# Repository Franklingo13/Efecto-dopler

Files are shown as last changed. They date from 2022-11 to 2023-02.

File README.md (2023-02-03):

# Radar de Velocidad Basado en el Efecto Doppler

Para este proyecto se emplea el efecto Doppler para calcular la velocidad de un objeto en base a la diferencia de frecuencias entre la enviada y la recibida.
El dispositivo empleado como transmisor y receptor es el sensor de movimiento CDM324, el cual funciona a una frecuecia de 24GHz. Este sensor también incorpora un mezclador de altas frecuencias y su salida es de unos pocos milivoltios, razón por la cual debe ser amplificada.

Se basó en el siguiente trabajo: https://github.com/limpkin/cdm324_backpack.

## _Primera Versión_
- Usa arduino Mega.
- Calcula la frecuencia recibida mediante usando la función _pulsein_.
- Presenta la velocidad en una pequeña pantalla OLED

### Amplificador 

Para el amplificador se usó el operacional LM358 alimentado a 5V y consta de dos etapas, la primera pre-amplifica la señal y en la segunda se obtiene una señal cuadrada. 
La simulación en Proteus de este circuito se encuentra en _Sim_Proteus/Circuito_amplificador.pdsprj_

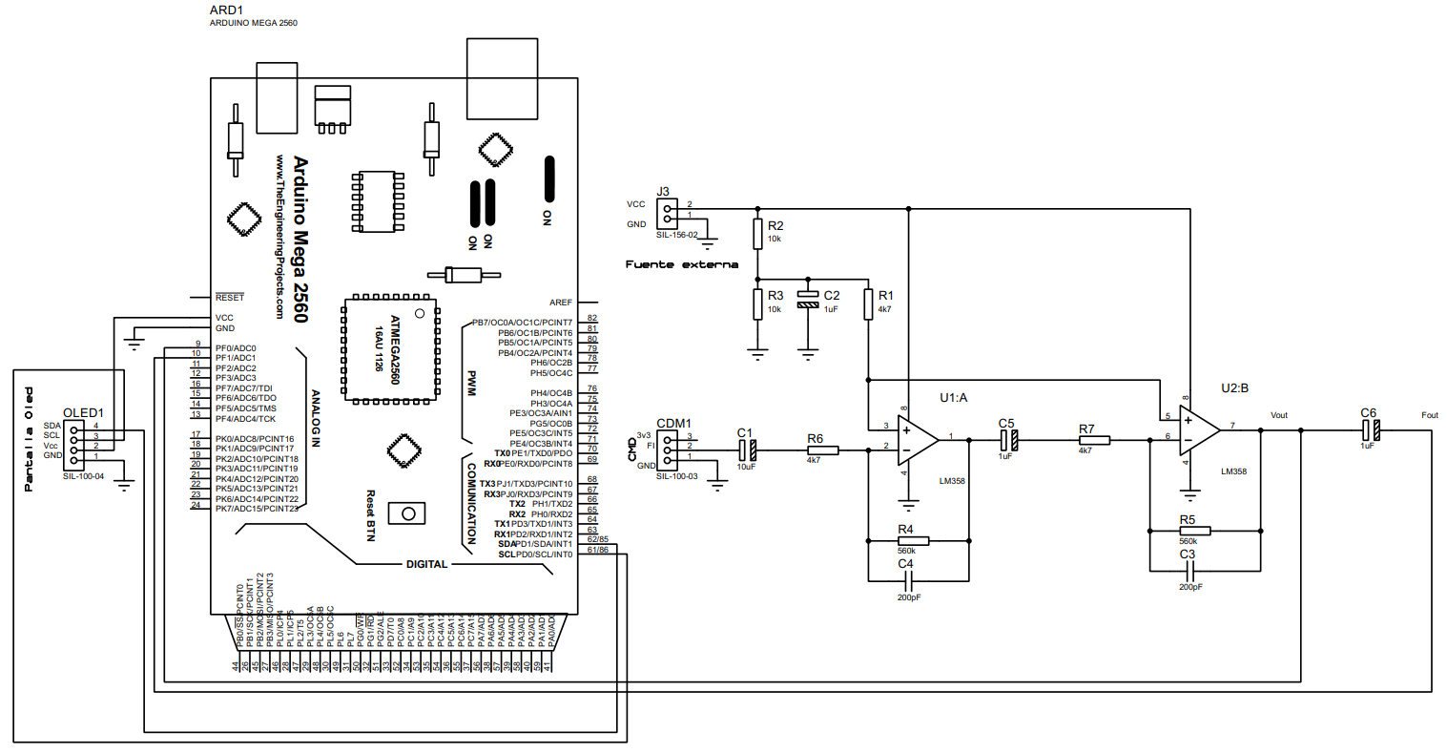
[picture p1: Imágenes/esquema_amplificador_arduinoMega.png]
Esquema de la primera versión del amplificador


### Código arduino

Para calcular la frecuencia de un objeto se mide el ancho de cada pulso de la señal recibida en el Arduino para calcular el periodo de la señal y así tener su frecuencia Doppler, con la que ya se puede calcular la velocidad. El código para implementar este método está en _Codigo arduino/contador_frecuencia_ .

### Placa PCB
En la carpeta de _Esquemáticos_ se puede encontrar el gerber de la siguiente placa PCB.

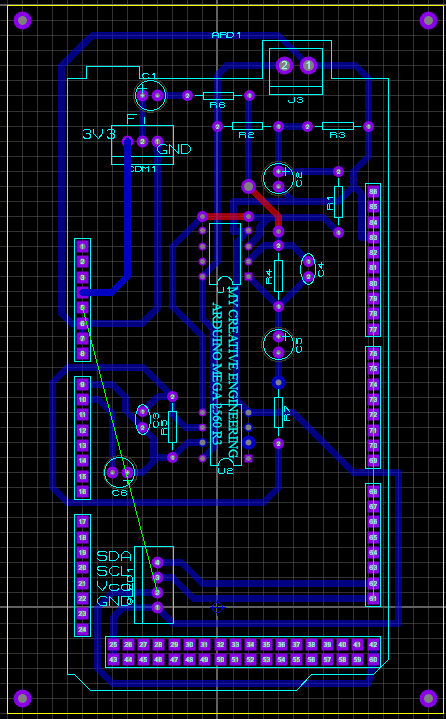
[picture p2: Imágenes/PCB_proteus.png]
Priemra versión de placa PCB


### Soporte 3D

Las piezas para el soporte impreso en 3D mostrado a continuación se encuentran en la carpeta _Piezas_.
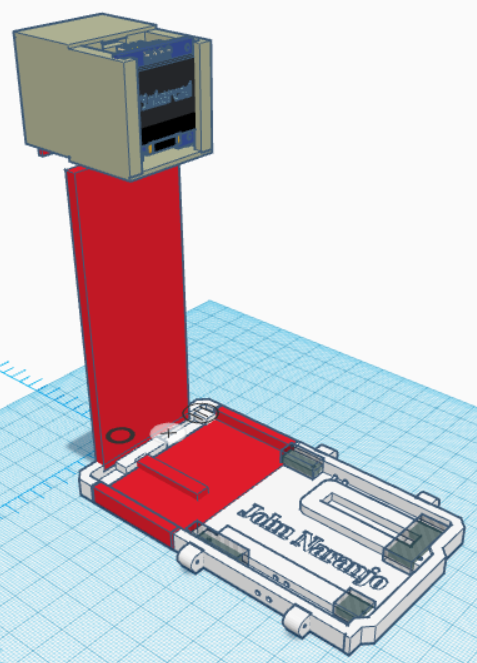
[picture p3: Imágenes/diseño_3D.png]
Primera versión del soporte


## _Segunda versión_
- Usa un ESP32.
- Calcula la frecuencia recibida mediante FFT.
- Presenta la velocidad en una pequeña pantalla OLED
- Envia los datos a un servicio en la nube para poder revisar la velocidad desde cualquier dispositivo con acceso a internet.

### Amplificador 

El esquema del amplificador y sus conexiones con el ESP32 se muestran a continuación.

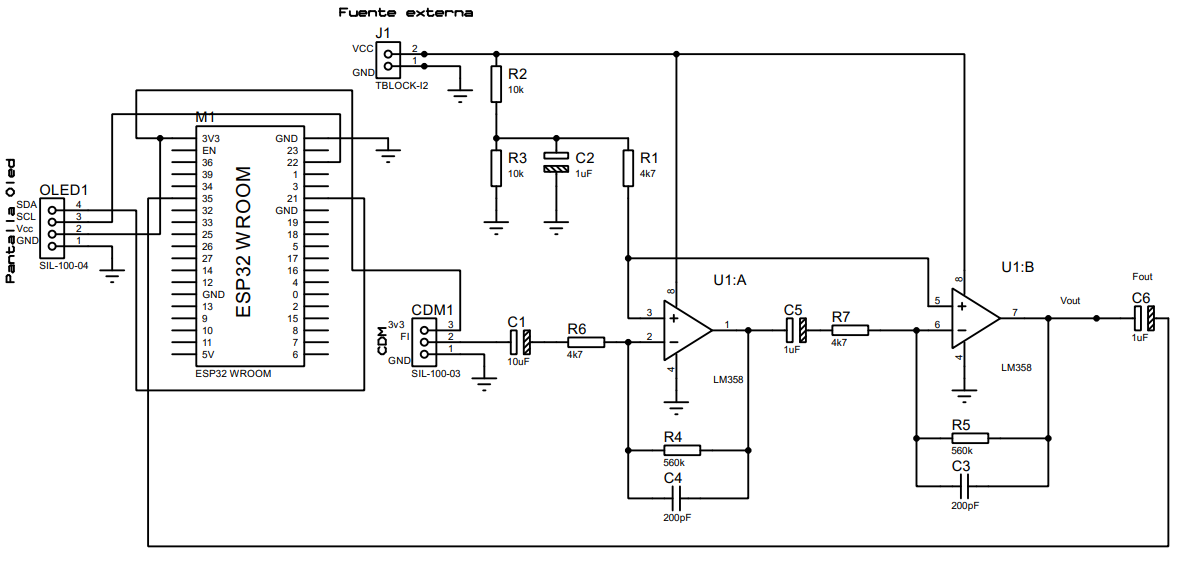
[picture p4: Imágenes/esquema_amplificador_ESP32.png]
Esquema de la segunda versión del amplificador


### Código arduino

Para encontrar la velocidad se calcula la FFT de la señal recibida empleando la librería arduinoFFT.h, además de presentar los datos en una pantalla OLED, también los envía al servicio en la nube de Thinger.io.  El código para implementar este método está en _Codigo arduino/final_esp32_FFT_ .

### Placa PCB
La versión final de la placa PCB se muestra a continuación y sus archivos Gerber están en la carpeta de _Esquemáticos_
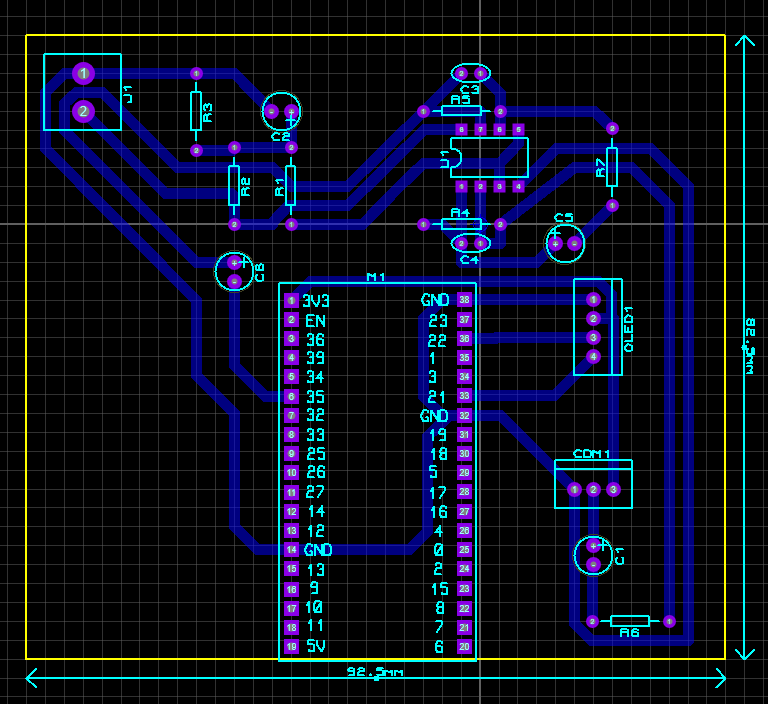
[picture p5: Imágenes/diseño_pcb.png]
segunda versión de placa PCB


### Soporte 3D

Las piezas de la segunda versión del soporte se encuentran en la carpeta _Piezas radar final_ESP32_.

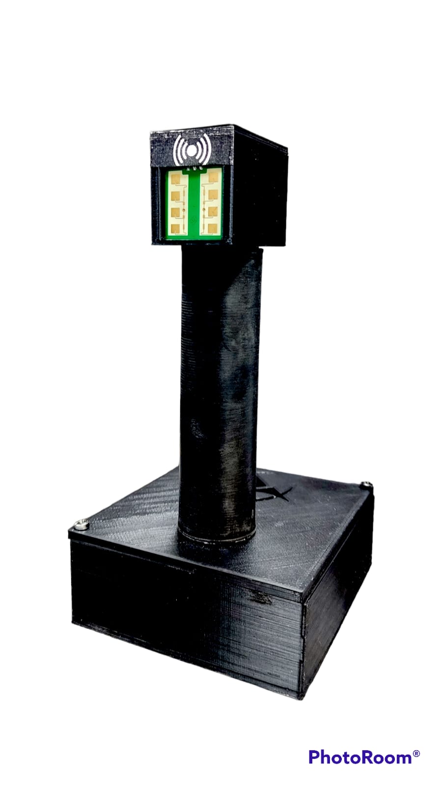
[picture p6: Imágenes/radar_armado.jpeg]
Segunda versión del soporte


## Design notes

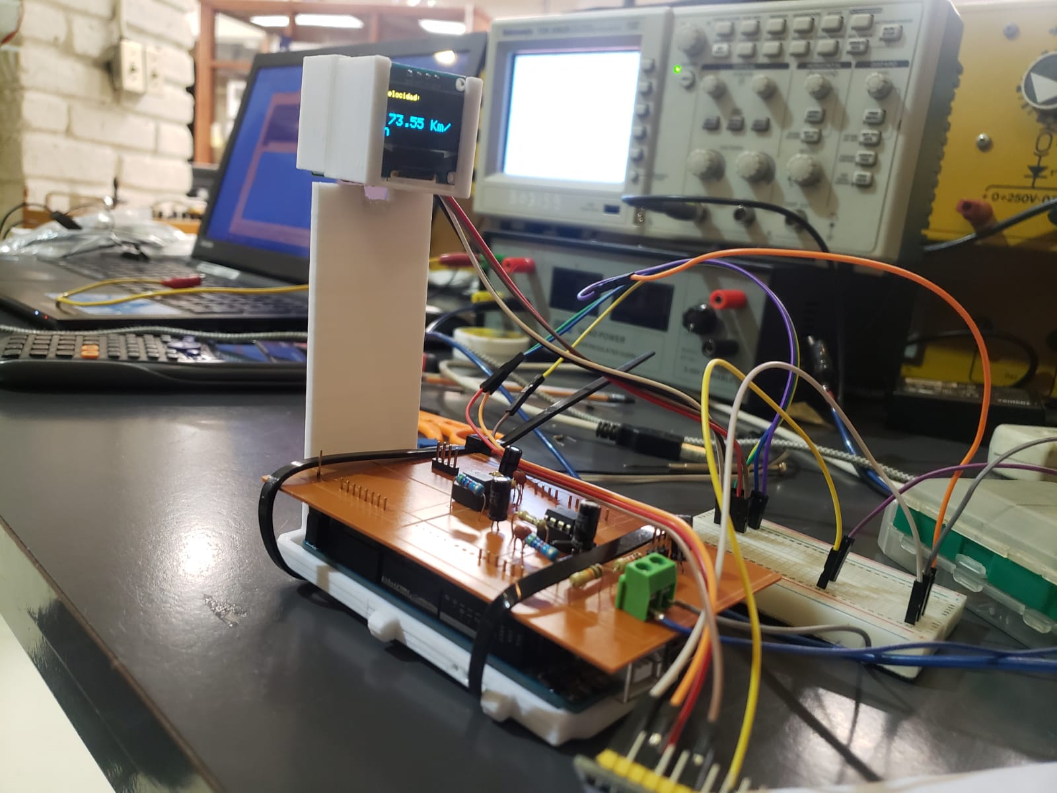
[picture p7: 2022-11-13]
Imágenes/diseño_implementado.jpeg

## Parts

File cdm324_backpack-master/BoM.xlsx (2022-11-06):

 | Prototype Quantity | 10
Item | References | Qty | Manufacturer P/N | Manufacturer | Description | Package | Internet Link | Home ID | Part Status
1 | U1 | 1 | OPA2365AIDR | Texas Instruments | IC OPAMP GP 50MHZ RRO 8SOIC | 8-SOIC | http://www.digikey.com/product-detail/en/OPA2365AIDR/296-31704-1-ND/3505181 | ---- | Active
2 | R2 R3 R10 R11 R1 | 5 | RC0805FR-0710KL | Yageo | RES SMD 10K OHM 1% 1/8W 0805 | 0805 | http://www.digikey.com/product-detail/en/yageo/RC0805FR-0710KL/311-10.0KCRCT-ND/730482 | ---- | Active
3 | FB1 | 1 | HZ0805D102R-10 | Laird-Signal Integrity Products | FERRITE BEAD 1 KOHM 0805 1LN | 0805 (2012 Metric) | http://www.digikey.com/product-detail/en/HZ0805D102R-10/240-2397-1-ND/806757 | ---- | Active
4 | P2 | 1 | PPPC031LFBN-RC | Sullins Connector Solutions | CONN HEADER FEMALE 3POS .1" GOLD |  | http://www.digikey.com/product-detail/en/sullins-connector-solutions/PPPC031LFBN-RC/S7036-ND/810175 | ---- | Active
5 | C3 C4 C1 C2 C8 C5 C9 C11 C10 | 9 | CL21B106KOQNNNE | Samsung Electro-Mechanics America, Inc. | CAP CER 10UF 16V X7R 0805 | 0805 (2012 Metric) | http://www.digikey.com/product-detail/en/samsung-electro-mechanics-america-inc/CL21B106KOQNNNE/1276-2872-1-ND/3890958 | ---- | Active
6 | R4 R5 R6 | 3 | RC0805FR-074K7L | Yageo | RES SMD 4.7K OHM 1% 1/8W 0805 | 0805 | http://www.digikey.com/product-detail/en/yageo/RC0805FR-074K7L/311-4.70KCRCT-ND/730876 | ---- | Active
7 | R7 R8 | 2 | ERJ-6ENF5903V | Panasonic Electronic Components | RES SMD 590K OHM 1% 1/8W 0805 | 0805 | http://www.digikey.com/product-detail/en/panasonic-electronic-components/ERJ-6ENF5903V/P590KCCT-ND/119773 | ---- | Active
8 | C6 C7 | 2 | CC0805JRNPO9BN271 | Yageo | CAP CER 270PF 50V NPO 0805 | 0805 (2012 Metric) | http://www.digikey.com/product-detail/en/yageo/CC0805JRNPO9BN271/311-1116-1-ND/303026 | ---- | Active
9 | U2 | 1 | MAX9031AUK+T | Maxim Integrated | IC COMPARATOR VOLT SGL SOT23-5 | SOT-23-5 | http://www.digikey.com/product-detail/en/MAX9031AUK%2BT/MAX9031AUK%2BTCT-ND/774161 | ---- | Active
10 | R9 | 1 | RC0805FR-078K2L | Yageo | RES SMD 8.2K OHM 1% 1/8W 0805 | 0805 | http://www.digikey.com/product-detail/en/yageo/RC0805FR-078K2L/311-8.20KCRCT-ND/731094 | ---- | Active
11 | D1 | 1 | S1B-13-F | Diodes Incorporated | DIODE GEN PURP 100V 1A SMA | SMA | http://www.digikey.com/product-detail/en/diodes-incorporated/S1B-13-F/S1B-FDICT-ND/725064 | ---- | Active
12 | Q1 | 1 | DMP3098L-7 | Diodes Incorporated | MOSFET P-CH 30V 3.8A SOT23-3 | SOT-23-3 | http://www.digikey.com/product-detail/en/diodes-incorporated/DMP3098L-7/DMP3098LDICT-ND/1964773 | ---- | Active
13 | P1 | 1 |  |  | Standard 5x1 0.1" straight male header
 | Total: | 28

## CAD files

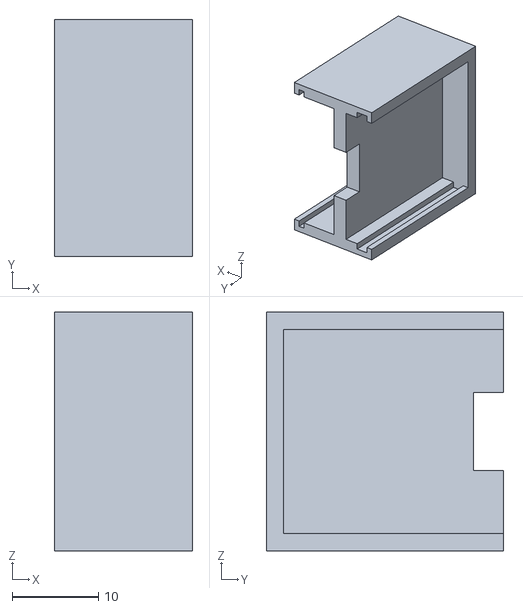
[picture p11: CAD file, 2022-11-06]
cdm324_backpack-master/mechanics/assembly.STL
16.0 x 27.5 x 27.7

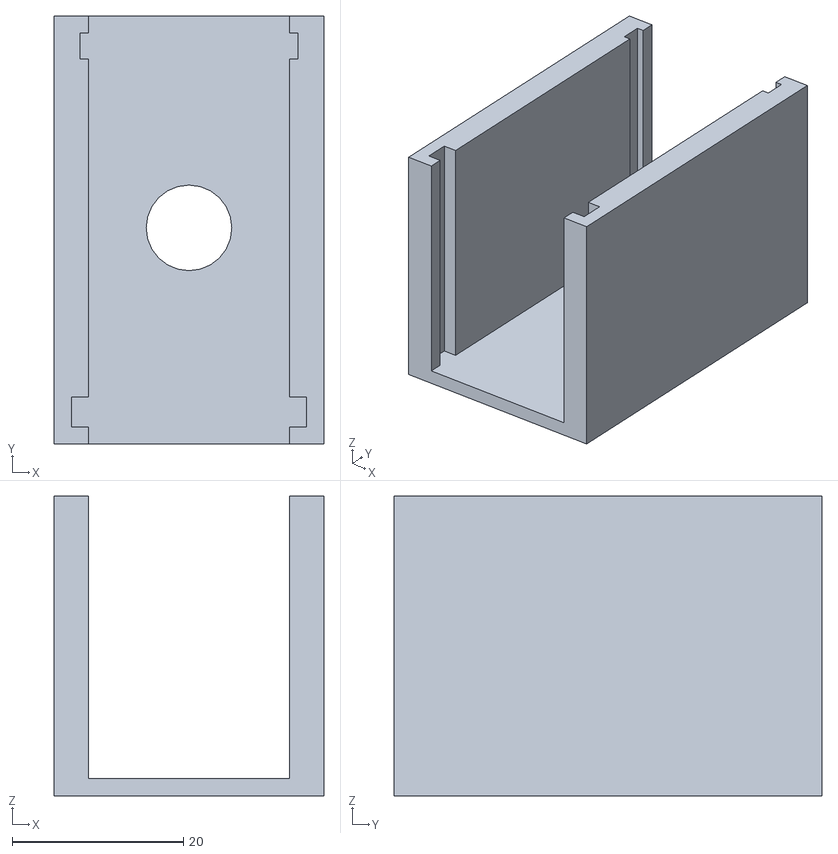
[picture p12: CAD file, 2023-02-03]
Piezas radar final_ESP32/Cabezal.stl
31.5 x 50.0 x 35.0

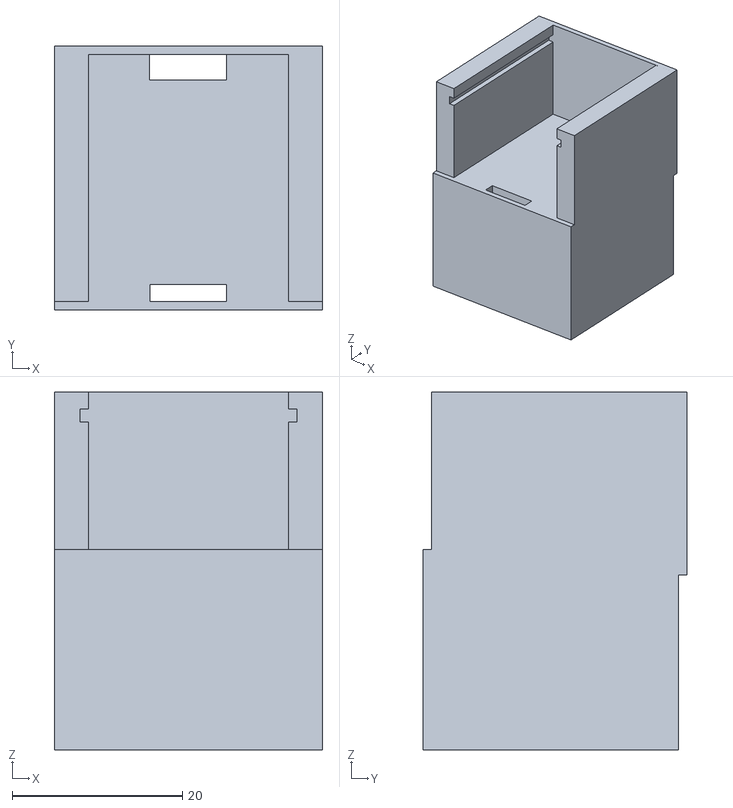
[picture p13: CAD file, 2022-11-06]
Piezas/piezas_final-BodyPad002.stl
31.5 x 31.0 x 42.0

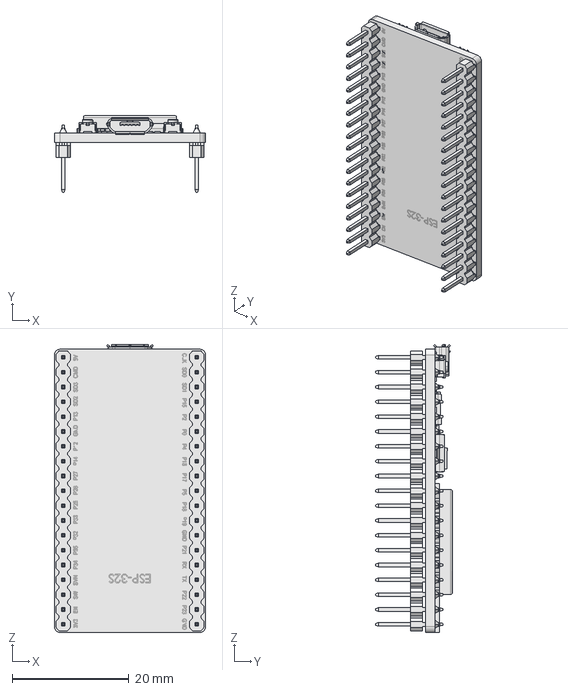
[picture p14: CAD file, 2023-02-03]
Piezas radar final_ESP32/esp32_3d.FCStd
25.9 x 13.1 x 49.3 mm

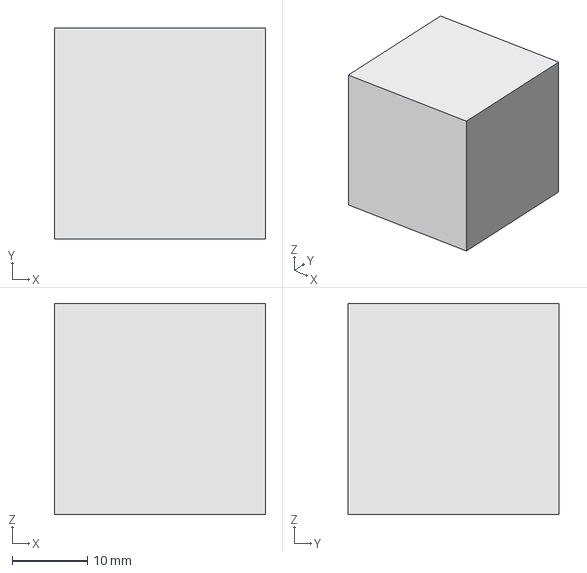
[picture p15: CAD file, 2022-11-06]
Piezas/pieza1.FCStd
28.0 x 28.0 x 28.0 mm

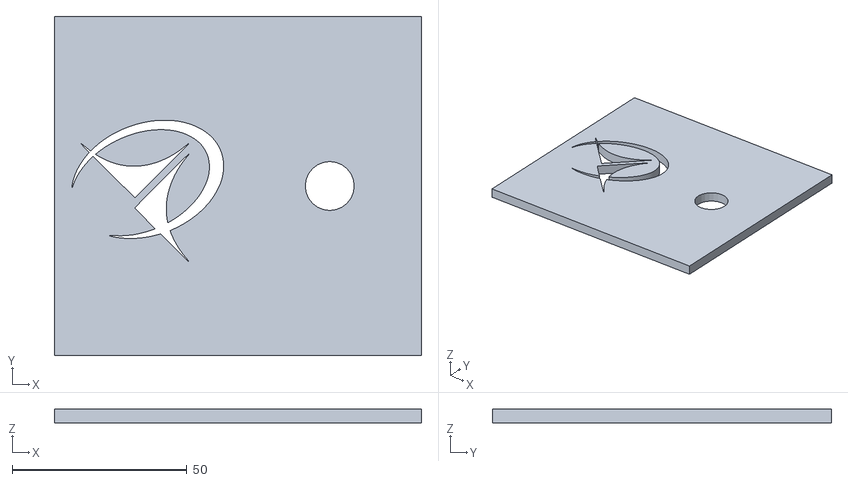
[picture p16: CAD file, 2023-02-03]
Piezas radar final_ESP32/Tapa.stl
105.0 x 97.0 x 4.00

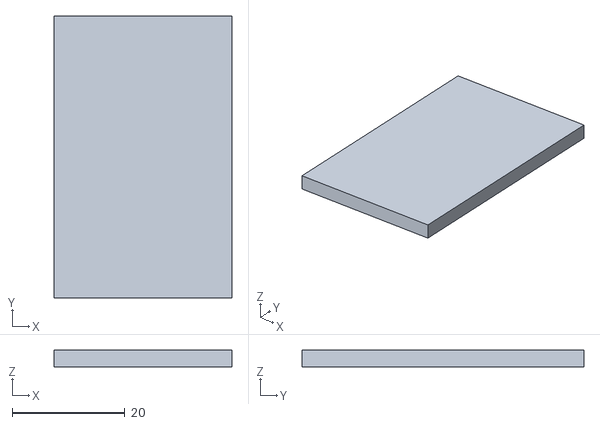
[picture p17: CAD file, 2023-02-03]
Piezas radar final_ESP32/TapaCabezal.stl
31.5 x 50.0 x 3.00

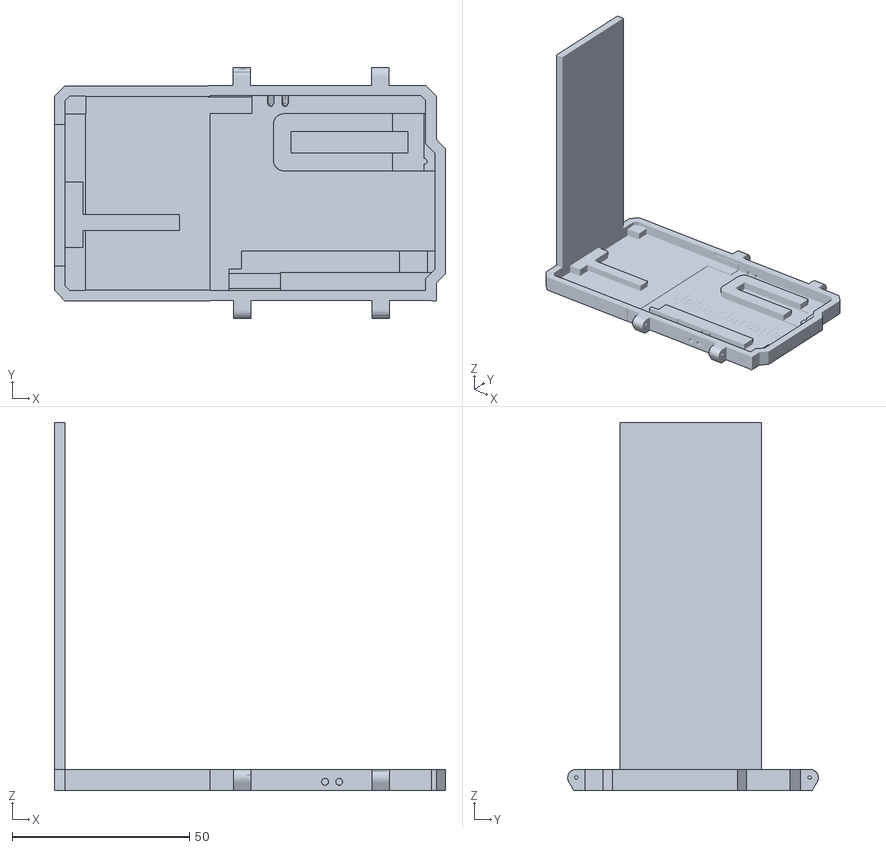
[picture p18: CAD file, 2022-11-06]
Piezas/base_arduino.stl
110.4 x 70.8 x 104.0

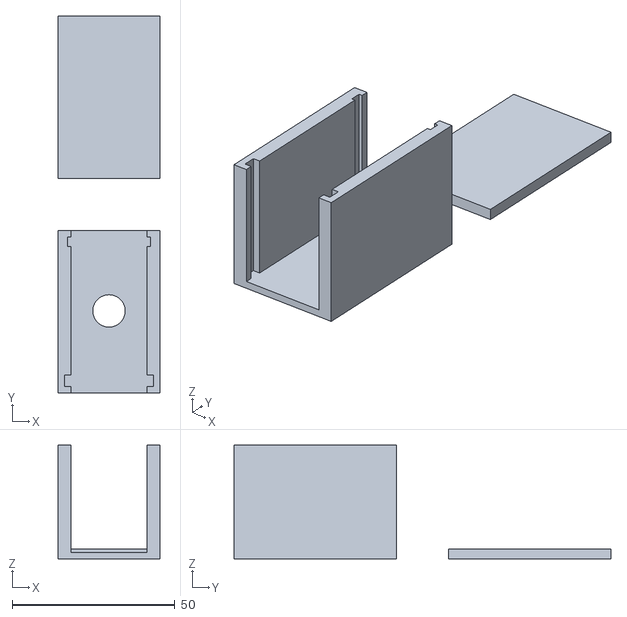
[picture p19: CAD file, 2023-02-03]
Piezas radar final_ESP32/cabezal_tapa.stl
31.5 x 116.0 x 35.0

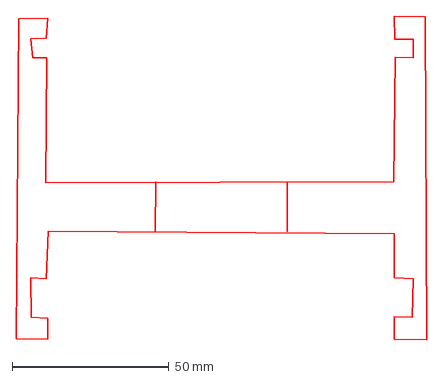
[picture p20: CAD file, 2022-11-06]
Piezas/medidas.dxf
130.8 x 103.3 mm

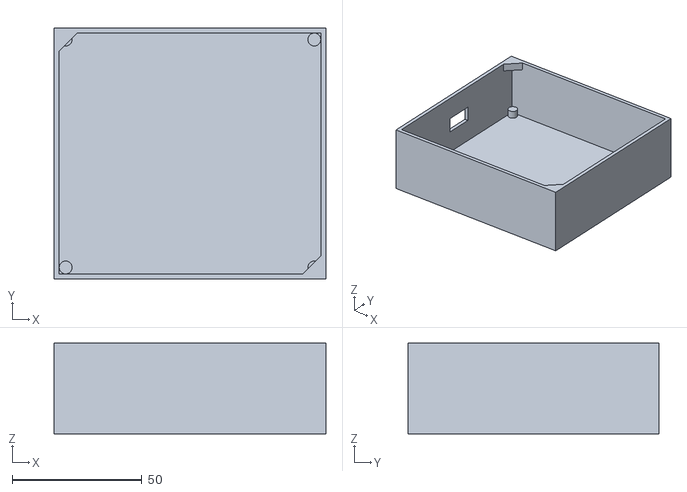
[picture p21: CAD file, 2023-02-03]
Piezas radar final_ESP32/Base.stl
105.0 x 97.0 x 35.0

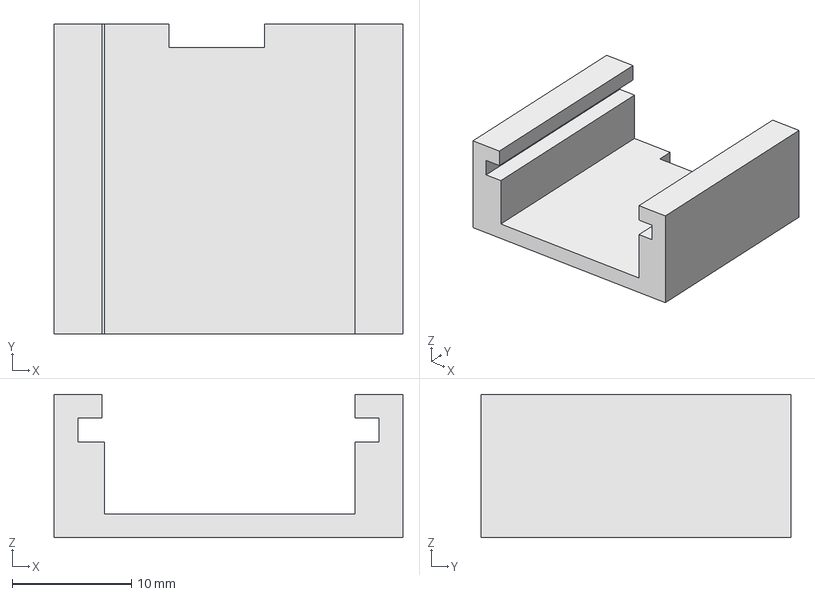
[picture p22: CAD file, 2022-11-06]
Piezas/extrusión.FCStd
29.2 x 26.0 x 12.0 mm

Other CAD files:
Piezas/pieza_sensor_oles.stl
Piezas/piezas_final.FCStd

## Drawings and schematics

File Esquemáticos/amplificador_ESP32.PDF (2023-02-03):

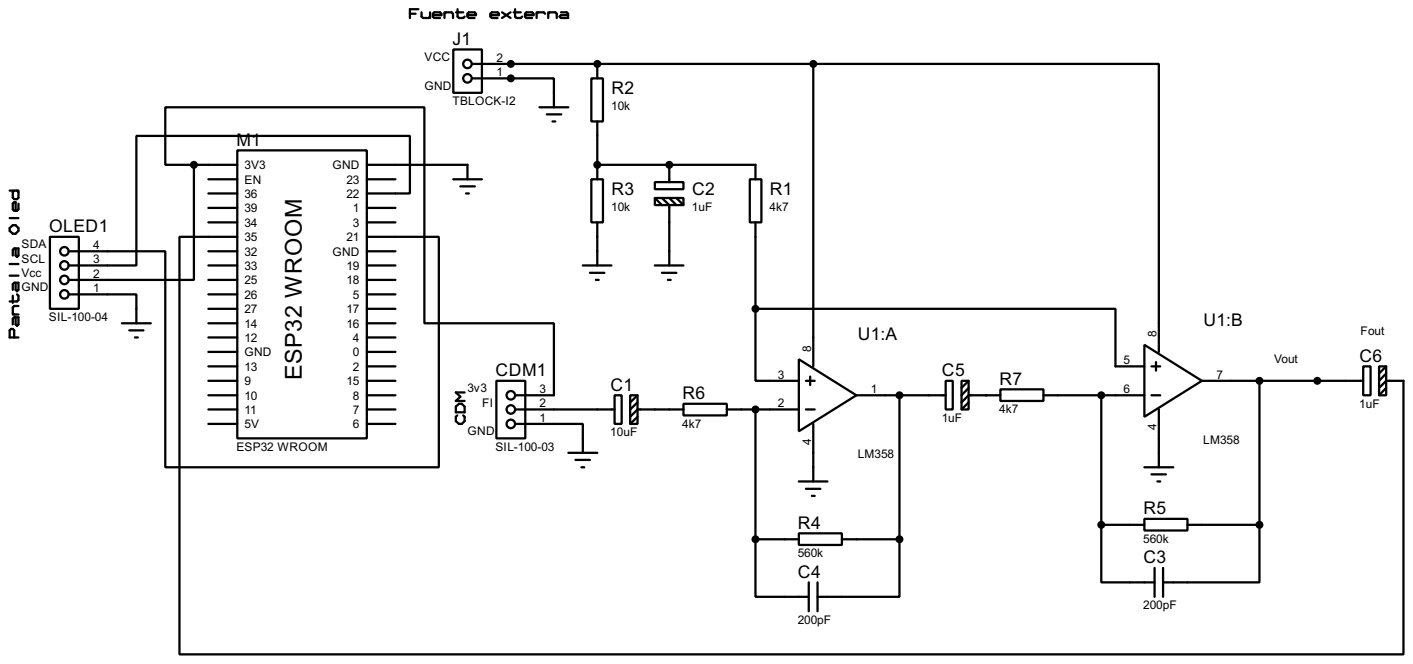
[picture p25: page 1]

ESP32 WROOM 3V3 EN3639343532332526271412GND 13910115V GND23221321 GND19185171640215876 M1 ESP32 WROOM R1 4k7 R2 10k R3 10k R4 560k R5 560k FI R6 4k7 C1 10uF C2 1uF 32 1 8 4 U1:A LM358 C3 200pF C4 200pF C5 1uF R7 4k7 56 7 8 4 U1:B LM358 Fout 123 CDM1 SIL-100-03 3v3 GND C6 1uF Vout VCC GND 1234 OLED1 SIL-100-04 SDA SCL Vcc GND 12 J1TBLOCK-I2

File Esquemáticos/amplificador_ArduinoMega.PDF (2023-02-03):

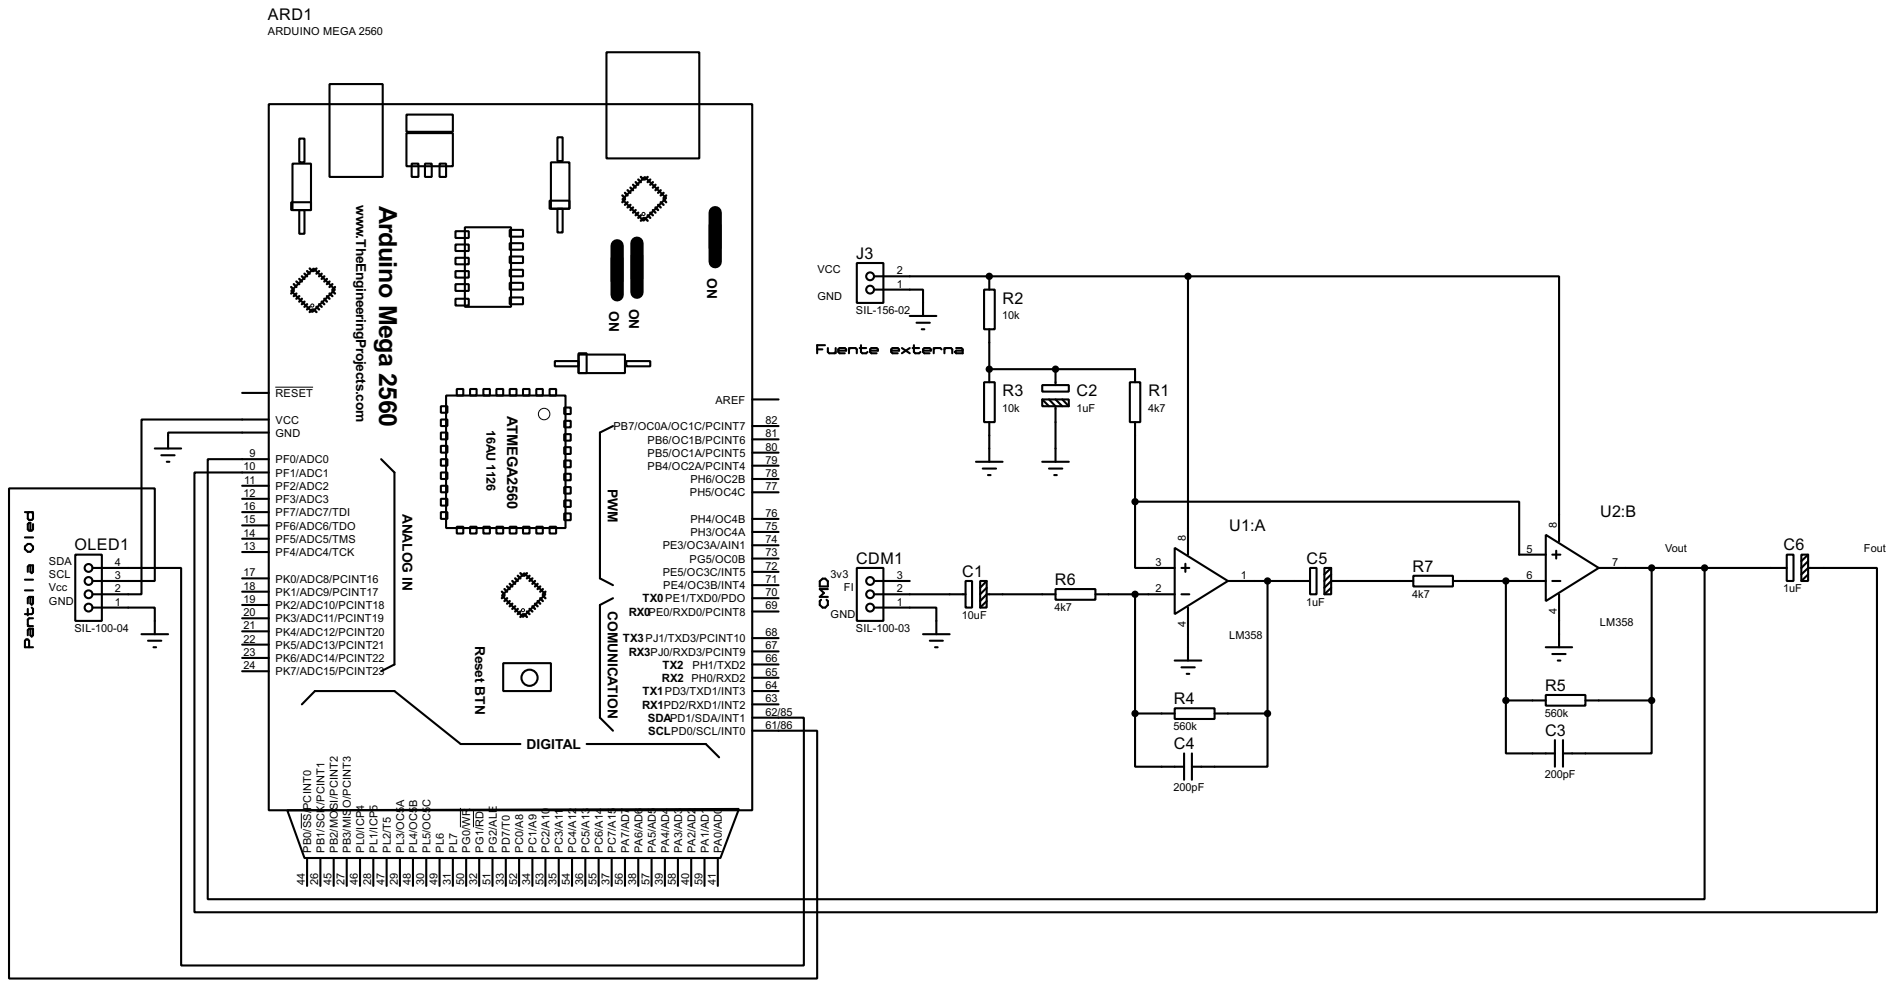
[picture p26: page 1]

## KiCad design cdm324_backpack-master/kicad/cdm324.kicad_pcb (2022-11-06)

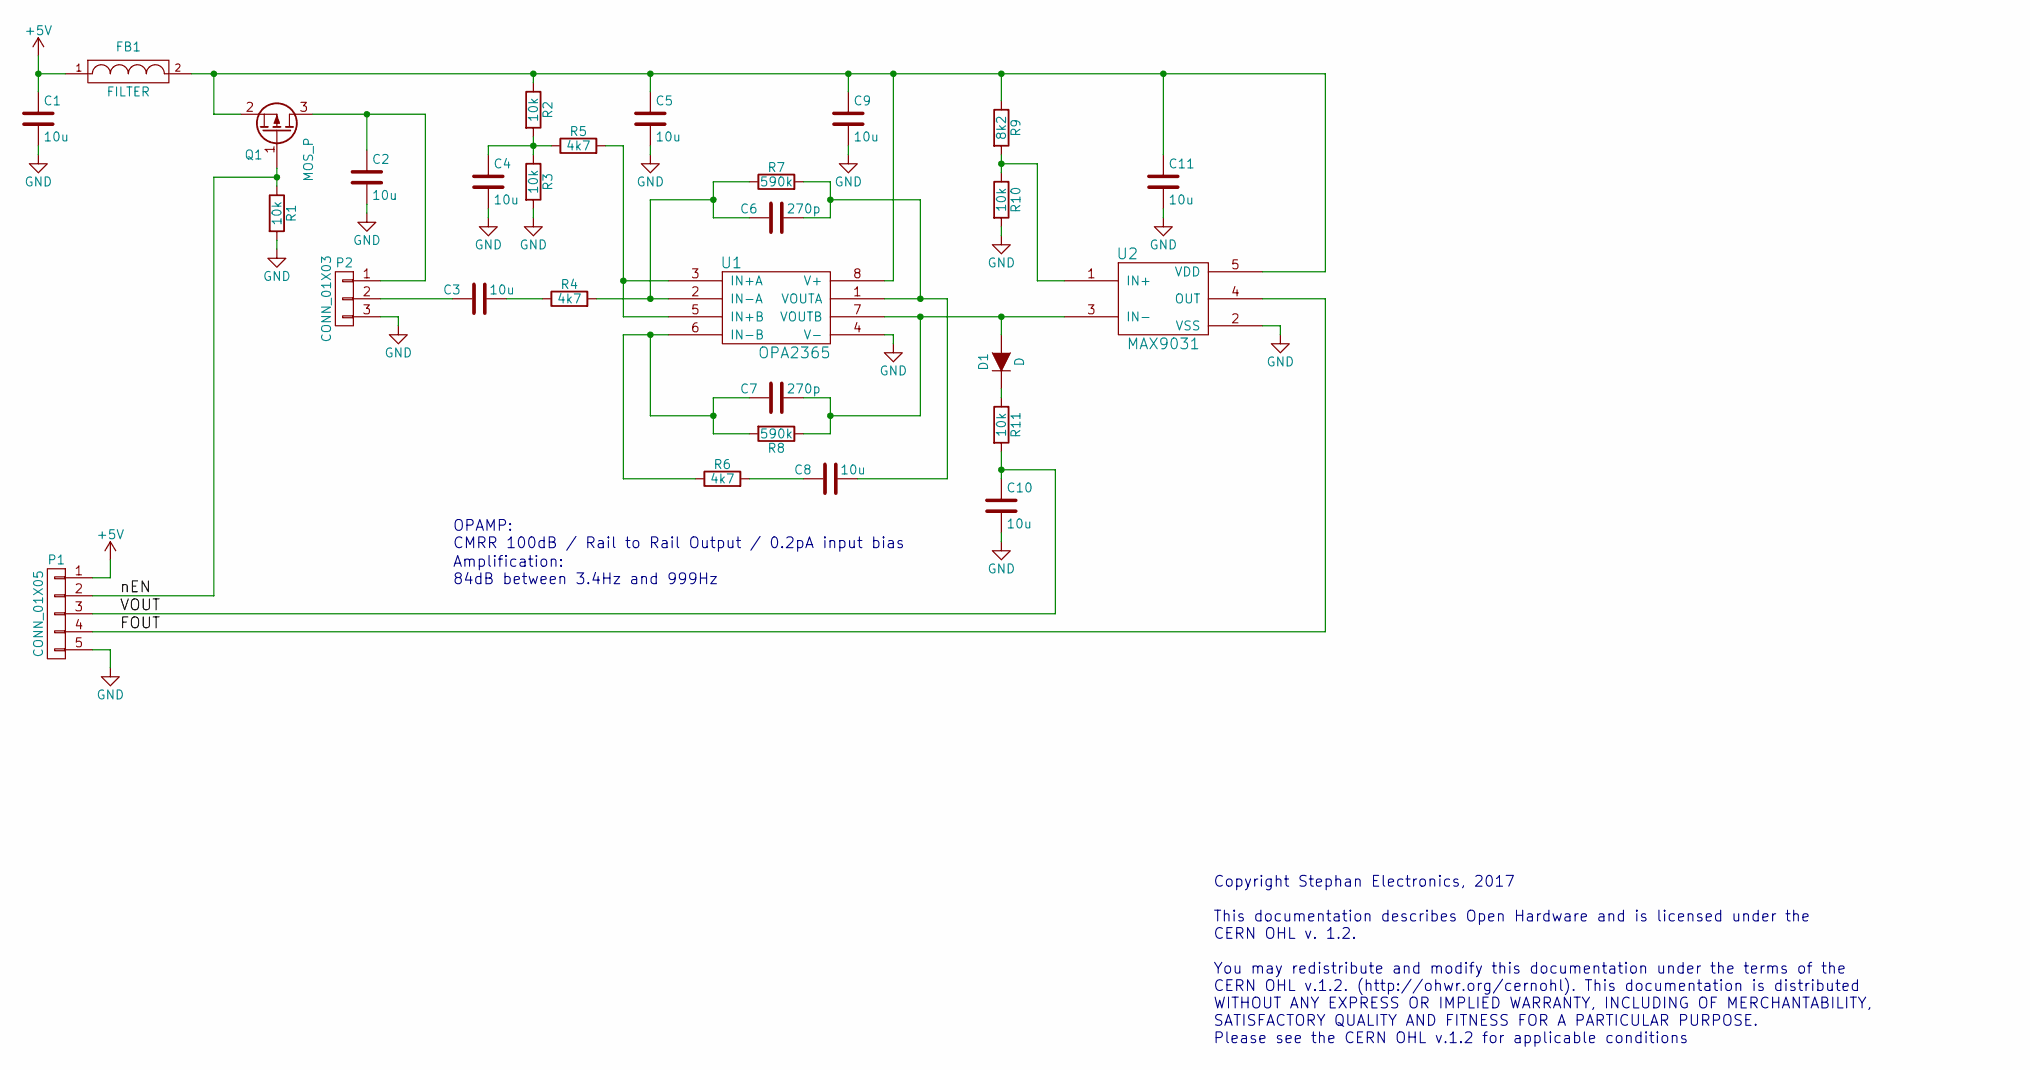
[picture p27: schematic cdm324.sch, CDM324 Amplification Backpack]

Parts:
C1, C2, C3, C4, C5, C8, C9, C10, C11: 10u; C_0805
C6, C7: 270p; C_0805
D1: D; DIODE_SMA
FB1: FILTER; C_0805
P1: CONN_01X05; Pin_Header_Straight_1x05_Pitch2.54mm
P2: CONN_01X03; Pin_Header_Straight_1x03_Pitch2.54mm
Q1: MOS_P; SOT23-3
R1, R2, R3, R10, R11: 10k; R_0805
R4, R5, R6: 4k7; R_0805
R7, R8: 590k; R_0805
R9: 8k2; R_0805
U1: OPA2365; SOIC-8-N
U2: MAX9031; SOT-23-5

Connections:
+5V: C1.1, FB1.1, P1.1
/FOUT: P1.4, U2.4 (OUT)
/VOUT: C10.1, P1.3, R11.2
/nEN: P1.2, Q1.1 (G), R1.1
GND: C1.2, C2.2, C4.2, C5.2, C9.2, C10.2, C11.2, P1.5, P2.3, R1.2, R3.2, R10.2, U1.4 (V-), U2.2 (VSS)
unnamed: C2.1, P2.1, Q1.3 (D)
unnamed: C3.1, P2.2
unnamed: C3.2, R4.1
unnamed: C4.1, R2.2, R3.1, R5.1
unnamed: C6.1, R4.2, R7.1, U1.2 (IN-A)
unnamed: C6.2, C8.2, R7.2, U1.1 (VOUTA)
unnamed: C7.1, R6.1, R8.2, U1.6 (IN-B)
unnamed: C7.2, D1.2 (A), R8.1, U1.7 (VOUTB), U2.3 (IN-)
unnamed: C8.1, R6.2
unnamed: C5.1, C9.1, C11.1, FB1.2, Q1.2 (S), R2.1, R9.1, U1.8 (V+), U2.5 (VDD)
unnamed: D1.1 (K), R11.1
unnamed: R5.2, U1.3 (IN+A), U1.5 (IN+B)
unnamed: R9.2, R10.1, U2.1 (IN+)

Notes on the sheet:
Amplification: 84dB between 3.4Hz and 999Hz
OPAMP: CMRR 100dB / Rail to Rail Output / 0.2pA input bias
Copyright Stephan Electronics, 2017 This documentation describes Open Hardware and is licensed under the CERN OHL v. 1.2. You may redistribute and modify this documentation under the terms of the CERN OHL v.1.2. (http://ohwr.org/cernohl). This documentation is distributed WITHOUT ANY EXPRESS OR IMP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

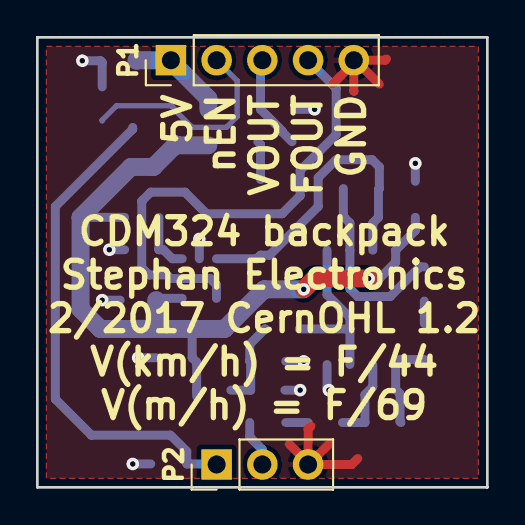
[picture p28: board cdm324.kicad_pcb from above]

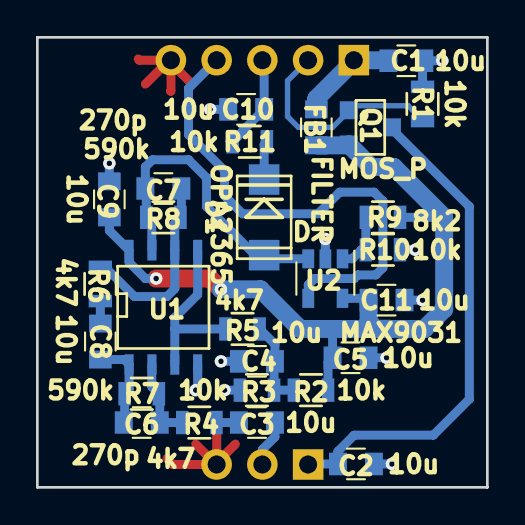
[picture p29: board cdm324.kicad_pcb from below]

Board: 2 copper layers, 25.0 x 25.0 mm, 29 parts (27 on the bottom side), 18 nets.

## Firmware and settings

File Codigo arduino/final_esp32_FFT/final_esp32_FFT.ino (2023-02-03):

#include <Wire.h>
#include <Adafruit_GFX.h>
#include <Adafruit_SSD1306.h>
#include "arduinoFFT.h"
#include "WiFi.h"
#include <ThingerESP32.h>


/*
These values can be changed in order to evaluate the functions
*/

/* FOR FFT */
#define CHANNEL 35
// PANTALLA OLED
#define ANCHO 128
#define ALTO 64
/* THING.IO */
#define THINGER_SERIAL_DEBUG
#define USERNAME "andresf5597"
#define DEVICE_ID "esp32"
#define DEVICE_CREDENTIAL "QyRdGD0eNm8#@pGP"


arduinoFFT FFT = arduinoFFT(); /* Create FFT object */
ThingerESP32 thing(USERNAME, DEVICE_ID, DEVICE_CREDENTIAL);

const uint16_t samples = 2048 ; //This value MUST ALWAYS be a power of 2
const double samplingFrequency = 4000; //Hz, must be less than 10000 due to ADC

unsigned int sampling_period_us;
unsigned long microseconds;

/*
These are the input and output vectors
Input vectors receive computed results from FFT
*/



double vReal[samples];
double vImag[samples];
float fd;
float vel;
#define SCL_INDEX 0x00
#define SCL_TIME 0x01
#define SCL_FREQUENCY 0x02
#define SCL_PLOT 0x03
#define OLED_RESET -1
Adafruit_SSD1306 oled(ANCHO,ALTO, &Wire, OLED_RESET);


// INICIALIZAR WIFI
const char* SSID = "POCOX3";
const char* SSID_PASWORD = "pocox5597";

unsigned long channelId = 1915797;
const char* WriteAPIKey = "Z2WF768I7D3PWMIK";



/* thing.io */

float yaw = 0; // defined as a global variable for thing.io

WiFiClient Client;

void setup()
{
  sampling_period_us = round(1000000*(1.0/samplingFrequency));
  Serial.begin(115200);
  while(!Serial);
  Serial.println("Ready");
//INICIAR CONEXION WIFI //



  WiFi.begin(SSID,SSID_PASWORD);


  while (WiFi.status() != WL_CONNECTED){
    delay(500);
    Serial.print("Conectando...");

   }
   Serial.print("Conectado");


  /* INICIAR OLED */
  Wire.begin();
  oled.begin(SSD1306_SWITCHCAPVCC,0x3C);
  oled.clearDisplay();


    //THING.IO//
 thing.add_wifi(SSID, SSID_PASWORD);
  Serial.print(" ");
  Serial.println("Ready_thing");
  //========//

}



void loop()
{

  /*SAMPLING*/
  microseconds = micros();




  for(int i=0; i<samples; i++)
  {
      vReal[i] = analogRead(CHANNEL);
      vImag[i] = 0;
      while(micros() - microseconds < sampling_period_us){
        //empty loop
      }
      microseconds += sampling_period_us;
  }



  //Serial.println("Data:");
//  PrintVector(vReal, samples, SCL_TIME);
  FFT.Windowing(vReal, samples, FFT_WIN_TYP_HAMMING, FFT_FORWARD);
  //Serial.println("Weighed data:");
 // PrintVector(vReal, samples, SCL_TIME);
  FFT.Compute(vReal, vImag, samples, FFT_FORWARD);
  //Serial.println("Computed Real values:");
 // PrintVector(vReal, samples, SCL_INDEX);
  //Serial.println("Computed Imaginary values:");
 // PrintVector(vImag, samples, SCL_INDEX);
  FFT.ComplexToMagnitude(vReal, vImag, samples);
  //Serial.println("Computed magnitudes:");
//  PrintVector(vReal, (samples >> 1), SCL_FREQUENCY);


  double x = FFT.MajorPeak(vReal, samples, samplingFrequency);
  Serial.println("");
  Serial.println(x, 6); //Print out what frequency is the most dominant.
  fd=x;
  vel=fd/44;
  Serial.print(fd/44);Serial.print("km/h");




  // THING.IO //
      //PARAMETROS PARA PLATAFORMA IOT
  yaw = vel;
  thing["tempC"] >> [](pson& out){
      out = yaw;
  };
// thing.handle();


  //IMPRIMIR VALORES EN OLED//
      oled.clearDisplay();
      oled.setTextColor(WHITE); //NO MULTIPLES COLORES
      oled.setCursor(0,0); //ELIGE COORDENADAS PARA COMENEZAR A ESCRIBIR
      oled.setTextSize(1); //TAMAÑO DEL TEXTO
      oled.print("Velocidad:");
      oled.setCursor(10,30); // NUEVAS COORDENADAS
      oled.setTextSize(2);   //TAMAÑO DE TEXTO
      oled.print(vel);
      oled.print(" Km/h");
      oled.display();





  //while(1); /* Run Once */
  delay(1000); /* Repeat after delay */
}

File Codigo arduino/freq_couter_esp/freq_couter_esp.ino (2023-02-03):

#include <Wire.h>
#include <Adafruit_GFX.h>
#include <Adafruit_SSD1306.h>
#include "WiFi.h"
#include <ThingerESP32.h>
// Below: pin para la lectura de frecuencia
#define PIN_NUMBER 35
// numero de muestras para promediar
#define AVERAGE 4


#define ANCHO 128
#define ALTO 64


#define OLED_RESET -1 
Adafruit_SSD1306 oled(ANCHO,ALTO, &Wire, OLED_RESET);


//#include "ThingSpeak.h"
#include "WiFi.h"

/* THING.IO */
#define THINGER_SERIAL_DEBUG
#define USERNAME "andresf5597"
#define DEVICE_ID "esp32"
#define DEVICE_CREDENTIAL "QyRdGD0eNm8#@pGP"
ThingerESP32 thing(USERNAME, DEVICE_ID, DEVICE_CREDENTIAL);
unsigned int doppler_div = 44;
unsigned int samples[AVERAGE];
unsigned int x;
float vel;


// INICIALIZAR WIFI
const char* SSID = "POCOX3";
const char* SSID_PASWORD = "pocox5597"; 

unsigned long channelId = 1915797;
const char* WriteAPIKey = "Z2WF768I7D3PWMIK";

/* thing.io */ 

float yaw = 0; // defined as a global variable for thing.io


WiFiClient Client; 




int b = 0;  // bandera para el display 
int retraso = 5000;
//const unsigned char prueba [] PROGMEM = {
//  0xff, 0xff, 0xff, 0xff, 0xfc, 0x00, 0x00, 0x00, 0x00, 0x00, 0x00, 0x3f, 0xff, 0xff, 0xff, 0xff, 
//  0xff, 0xff, 0xff, 0xff, 0xfc, 0x00, 0x00, 0x00, 0x00, 0x0d, 0x7c, 0x3f, 0xff, 0xff, 0xff, 0xff, 
//  0xff, 0xff, 0xff, 0xff, 0xfc, 0x0f, 0xc0, 0x18, 0x00, 0x08, 0x8c, 0x3f, 0xff, 0xff, 0xff, 0xff, 
//  0xff, 0xff, 0xff, 0xff, 0xfc, 0x3f, 0xf0, 0x78, 0x00, 0x00, 0x00, 0x3f, 0xff, 0xff, 0xff, 0xff, 
//  0xff, 0xff, 0xff, 0xff, 0xfc, 0x7f, 0xfd, 0xf8, 0x00, 0x00, 0x00, 0x3f, 0xff, 0xff, 0xff, 0xff, 
//  0xff, 0xff, 0xff, 0xff, 0xfc, 0xfc, 0x1f, 0xf8, 0x00, 0x3c, 0x00, 0x3f, 0xff, 0xff, 0xff, 0xff, 
//  0xff, 0xff, 0xff, 0xff, 0xfc, 0xff, 0xc7, 0xe6, 0x00, 0x00, 0x00, 0x3f, 0xff, 0xff, 0xff, 0xff, 
//  0xff, 0xff, 0xff, 0xff, 0xfd, 0xef, 0xc3, 0xef, 0x01, 0xe0, 0x00, 0x3f, 0xff, 0xff, 0xff, 0xff, 
//  0xff, 0xff, 0xff, 0xff, 0xfd, 0xff, 0x01, 0xcf, 0x80, 0x01, 0x00, 0x3f, 0xff, 0xff, 0xff, 0xff, 
//  0xff, 0xff, 0xff, 0xff, 0xfd, 0xfe, 0x00, 0xe7, 0xf8, 0x00, 0xc0, 0x3f, 0xff, 0xff, 0xff, 0xff, 
//  0xff, 0xff, 0xff, 0xff, 0xfd, 0xfc, 0x00, 0x6f, 0xf8, 0x38, 0x00, 0x3f, 0xff, 0xff, 0xff, 0xff, 
//  0xff, 0xff, 0xff, 0xff, 0xfc, 0xf8, 0x00, 0x3f, 0xf8, 0x78, 0x00, 0x3f, 0xff, 0xff, 0xff, 0xff, 
//  0xff, 0xff, 0xff, 0xff, 0xfc, 0xf0, 0x04, 0x3f, 0xfc, 0x29, 0x00, 0x3f, 0xff, 0xff, 0xff, 0xff, 
//  0xff, 0xff, 0xff, 0xff, 0xfc, 0x78, 0x02, 0x3f, 0xdf, 0x79, 0x00, 0x3f, 0xff, 0xff, 0xff, 0xff, 
//  0xff, 0xff, 0xff, 0xff, 0xfc, 0x78, 0x0f, 0x3f, 0xfe, 0x0f, 0x00, 0x3f, 0xff, 0xff, 0xff, 0xff, 
//  0xff, 0xff, 0xff, 0xff, 0xfc, 0x28, 0x1b, 0x7f, 0xbc, 0x3f, 0x80, 0x3f, 0xff, 0xff, 0xff, 0xff, 
//  0xff, 0xff, 0xff, 0xff, 0xfc, 0x34, 0x3f, 0x79, 0x9c, 0x3f, 0x80, 0x3f, 0xff, 0xff, 0xff, 0xff, 
//  0xff, 0xff, 0xff, 0xff, 0xfc, 0x3c, 0x3f, 0xdf, 0xf8, 0x3f, 0x80, 0x3f, 0xff, 0xff, 0xff, 0xff, 
//  0xff, 0xff, 0xff, 0xff, 0xfc, 0x7c, 0x7f, 0x8f, 0xf8, 0x39, 0x80, 0x3f, 0xff, 0xff, 0xff, 0xff, 
//  0xff, 0xff, 0xff, 0xff, 0xfc, 0x78, 0x7f, 0xcf, 0xf0, 0x3f, 0x00, 0x3f, 0xff, 0xff, 0xff, 0xff, 
//  0xff, 0xff, 0xff, 0xff, 0xfc, 0x30, 0x3f, 0xcf, 0xb0, 0x3e, 0x00, 0x3f, 0xff, 0xff, 0xff, 0xff, 
//  0xff, 0xff, 0xff, 0xff, 0xfc, 0x00, 0x1f, 0xc4, 0x60, 0x7e, 0x00, 0x3f, 0xff, 0xff, 0xff, 0xff, 
//  0xff, 0xff, 0xff, 0xff, 0xfc, 0x00, 0x03, 0x83, 0xe0, 0x7e, 0x00, 0x3f, 0xff, 0xff, 0xff, 0xff, 
//  0xff, 0xff, 0xff, 0xff, 0xfc, 0x00, 0x79, 0x03, 0xe0, 0x3e, 0x60, 0x3f, 0xff, 0xff, 0xff, 0xff, 
//  0xff, 0xff, 0xff, 0xff, 0xfc, 0x00, 0x7c, 0x07, 0xf0, 0xc0, 0x70, 0x3f, 0xff, 0xff, 0xff, 0xff, 
//  0xff, 0xff, 0xff, 0xff, 0xfc, 0x00, 0x5c, 0x03, 0xf5, 0xc0, 0x78, 0x3f, 0xff, 0xff, 0xff, 0xff, 
//  0xff, 0xff, 0xff, 0xff, 0xfc, 0x00, 0x18, 0x00, 0xf3, 0xe6, 0x70, 0x3f, 0xff, 0xff, 0xff, 0xff, 
//  0xff, 0xff, 0xff, 0xff, 0xfc, 0x00, 0x00, 0x00, 0x63, 0xe7, 0xd8, 0x3f, 0xff, 0xff, 0xff, 0xff, 
//  0xff, 0xff, 0xff, 0xff, 0xfc, 0x00, 0x00, 0x00, 0x23, 0xff, 0xfc, 0x3f, 0xff, 0xff, 0xff, 0xff, 
//  0xff, 0xff, 0xff, 0xff, 0xfc, 0x00, 0x00, 0x00, 0x07, 0xff, 0xfe, 0x3f, 0xff, 0xff, 0xff, 0xff, 
//  0xff, 0xff, 0xff, 0xff, 0xfc, 0x00, 0x00, 0xc0, 0x17, 0xff, 0x7b, 0x3f, 0xff, 0xff, 0xff, 0xff, 
//  0xff, 0xff, 0xff, 0xff, 0xfc, 0x00, 0x02, 0x00, 0x0b, 0xf8, 0xfb, 0x3f, 0xff, 0xff, 0xff, 0xff, 
//  0xff, 0xff, 0xff, 0xff, 0xfc, 0x00, 0x00, 0x00, 0x1f, 0xfd, 0xfb, 0x3f, 0xff, 0xff, 0xff, 0xff, 
//  0xff, 0xff, 0xff, 0xff, 0xfc, 0x00, 0x00, 0x00, 0x1f, 0xff, 0xfc, 0xff, 0xff, 0xff, 0xff, 0xff, 
//  0xff, 0xff, 0xff, 0xff, 0xfc, 0x00, 0x00, 0x00, 0x1e, 0xfb, 0xfc, 0xff, 0xff, 0xff, 0xff, 0xff, 
//  0xff, 0xff, 0xff, 0xff, 0xfc, 0x00, 0x00, 0x00, 0x1e, 0x7e, 0x0f, 0xff, 0xff, 0xff, 0xff, 0xff, 
//  0xff, 0xff, 0xff, 0xff, 0xfc, 0x00, 0x00, 0x00, 0x0e, 0x7f, 0x5f, 0xff, 0xff, 0xff, 0xff, 0xff, 
//  0xff, 0xff, 0xff, 0xff, 0xfc, 0x00, 0x00, 0x40, 0x0c, 0x3f, 0x7f, 0xff, 0xff, 0xff, 0xff, 0xff, 
//  0xff, 0xff, 0xff, 0xff, 0xfc, 0x00, 0x00, 0x00, 0x0c, 0x3f, 0x73, 0xff, 0xff, 0xff, 0xff, 0xff, 
//  0xff, 0xff, 0xff, 0xff, 0xfc, 0x00, 0x00, 0x00, 0x0e, 0x1f, 0x71, 0xff, 0xff, 0xff, 0xff, 0xff, 
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
//};




void setup() {
  
  Serial.begin(115200);
  pinMode(PIN_NUMBER, INPUT);

//// INICAIR CONEXION WIFI // 
//
//  WiFi.begin(ssid,password); 
//  while (WiFi.status() != WL_CONNECTED){
//    delay(500);
//    Serial.print("Conectando...");
//    
//   }
//   Serial.print("Conectado");
//   //Iniciar ThingSpeak
//   ThingSpeak.begin(Client);  
   


/* INICIAR OLED */
  Wire.begin();
  oled.begin(SSD1306_SWITCHCAPVCC,0x3C);
  oled.clearDisplay();
  
    //THING.IO//
  thing.add_wifi(SSID, SSID_PASWORD);
  //========//

}
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

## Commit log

2022-11-06 Documentos y archivos del trabajo de antenas
    [Arduino_Mega.fzz, BoM.xlsx, assembly.STL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]
2022-11-07 Se agrega codigo de ejemplo de uso de WiFi y ThingSpeak
2022-11-08 Se agrega el código para realización de FFT
2022-11-13 Se eliminó la líne que enciende un led
2022-11-13 Versión final del PCB del amplificador
2022-11-13 Se crea una carpeta para las imágenes de pruebas y resultados
2022-11-13 Código final de FFT + OLED
2022-11-13 Se modifica la simulación del amplificador en transiente
2022-11-13 se cambia de carpeta la imagne de la 1ra prueba de velocidad
2023-02-03 Se agregan las últimas actualizaciones
    [Base.stl, Cabezal.stl, Tapa.stl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]
2023-02-03 Se agrega imágenes de los esquemas
2023-02-03 Se corrige error ortográfico en el nombre de la carpeta
    [Base.stl, Cabezal.stl, Tapa.stl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]
2023-02-03 Update README.md
    Se agrega los detalles de la primera versión del proyecto.
2023-02-03 So corrige problemas con el código final de ESP32
    [Base.stl, Cabezal.stl, Tapa.stl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]
2023-02-03 Update README.md
    Se agregan ciertas características de la segunda versión
2023-02-03 Se agregan fotos de las versiones finales de la PCB y del soporte
2023-02-03 Update README.md
    Se agregan las descripciones finales de la segunda versión
2025-06-06 [ImgBot] Optimize images
    *Total -- 922.19kb -> 756.64kb (17.95%)
    /Imágenes/diseño_pcb.png -- 74.23kb -> 19.45kb (73.81%)
    /Imágenes/PCB_proteus.png -- 60.08kb -> 29.09kb (51.58%)
    /Imágenes/prueba1_velocidad.png -- 26.58kb -> 18.49kb (30.42%)
    /Piezas/soporte.svg -- 0.91kb -> 0.67kb (26.18%)
    /Imágenes/esquema_amplificador_arduinoMega.png -- 165.97kb -> 126.44kb (23.82%)
    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
